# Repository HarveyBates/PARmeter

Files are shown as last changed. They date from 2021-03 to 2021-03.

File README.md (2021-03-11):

# PARmeter
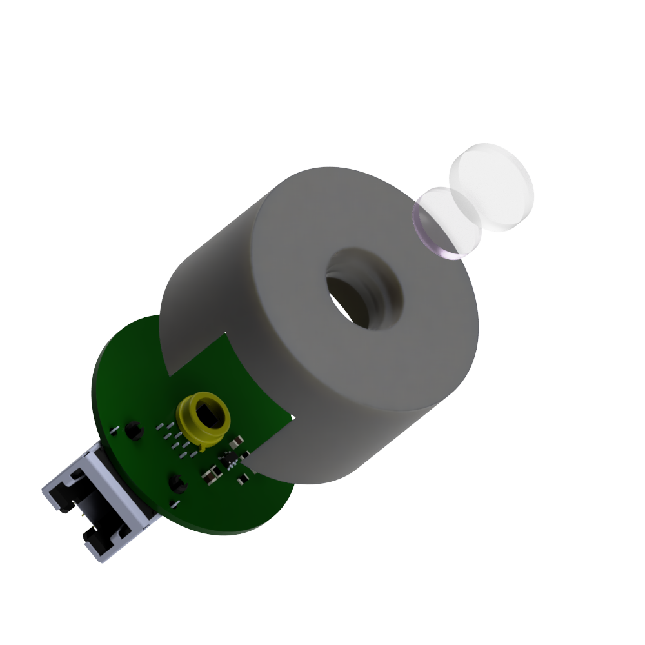
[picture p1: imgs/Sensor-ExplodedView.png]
## Introduction

**P**hotosynthetic **A**ctive **R**adiation (**PAR**) meters are designed to measure light intensity that has a wavelength between ~400 and 700 nm. This range represents the usable range for photosynthesising organims. This information is important for (amongst other things):

1. Studying photosynthesis
2. Calibrating plant growth light fixtures
3. Calibrating aqurarium LED arrays 

Readings are usually represented as the number of moles of photons per meter squared per second (**&mu;E m<sup>-2</sup> s<sup>-1</sup>** or **&mu;mol m<sup>-2</sup> s<sup>-1</sup>**). 

PAR meters differ from **l**uminous fl**ux** (**lux**) meters in that lux meters are typically used to measure wavelengths specific to human vision rather than those avaliable to photosynthesising organisms. Unlike PAR meters, lux meters require different coefficents for different light sources (white light, warm white light, blue, green, cyan etc.); therefore, they need to be calibrated for each light quality used. 

### Photodiode response

PAR meters are quite expensive when compared to lux meters as PAR meters require a virtually flat spectral response between the 400 and 700 nm wavelength range. This spectral response depends upon the photodiode used for detection. Typically, photodiodes have a varied wavelength specific response and as such only a few have ideal characteristics for PAR meters.

<p align="middle">
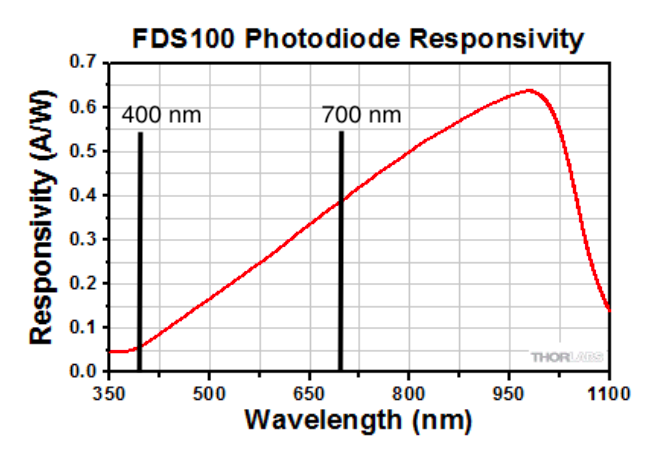
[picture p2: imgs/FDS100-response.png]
  
</p>

For this design I am using the [FDS100](https://www.thorlabs.com/thorproduct.cfm?partnumber=FDS100) (Silicon Photodiode) from ThorLabs. As its response is farily linear through the wavelength ranges of PAR. The increase in responsitivity with increasing wavelength is as a result of increasing [photon energy](https://en.wikipedia.org/wiki/Photon_energy).

### Cutoff filter

As can be seen from the photodiode responsitivity figure, the FDS100 photodiode is very responsive in wavelengths greater than 700 nm, therefore it is important that a short-pass filter is used to block these wavelengths from reaching the detector. 

<p align="middle">
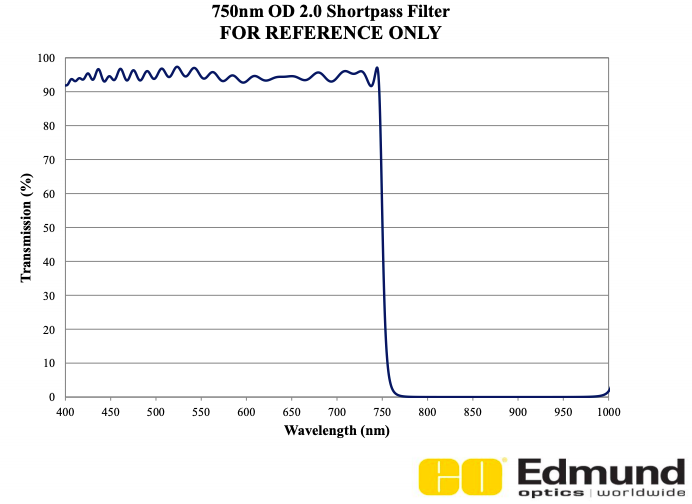
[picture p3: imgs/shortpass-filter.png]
  
</p>

Here I am using a 750 nm [short-pass filter](https://www.edmundoptics.com/p/750nm-125mm-dia-od-20-shortpass-filter/43482/) from Edmund optics. 750 nm is greater than the 400 - 700 nm range I mentioned earlier. However, the PAR range that is commonly used was determined a long time ago and there is evidence in the literature that IR-wavlengths are important to photosynthesis.

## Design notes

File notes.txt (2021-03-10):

------ Mechanical / Optical ------
Filter:
	https://www.edmundoptics.com/p/750nm-125mm-dia-od-20-shortpass-filter/43482/

Photodiode:
	https://www.thorlabs.com/thorproduct.cfm?partnumber=FDS100

Cosine Corrector (Acrylic Sheet):
	https://koenigmachinery.com.au/products/new-frosted-acrylic?variant=34646481240232

------ Electronics ------

Amplifier:
	https://au.element14.com/texas-instruments/opa320aidbvt/op-amp-cmos-20mhz-5sot23/dp/3116339?st=opa320

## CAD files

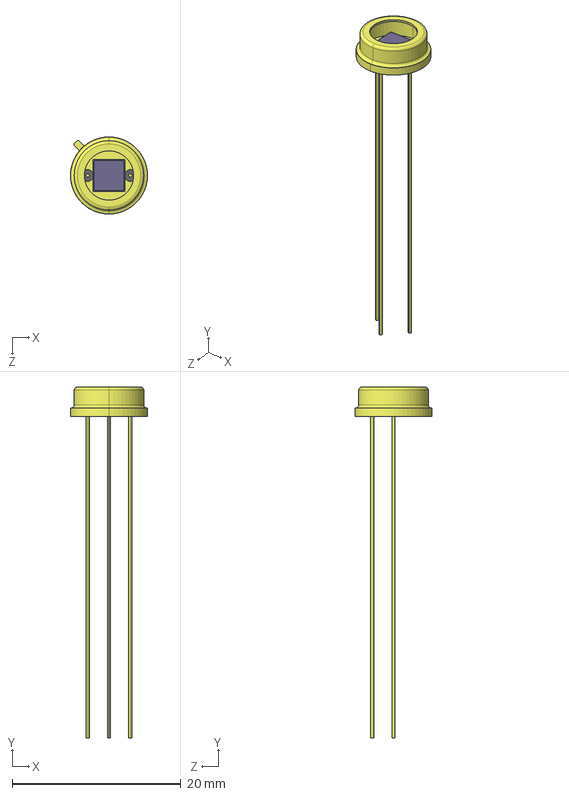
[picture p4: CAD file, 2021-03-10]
electronics/customlibrary/FDS100.step
9.14 x 41.6 x 9.14 mm

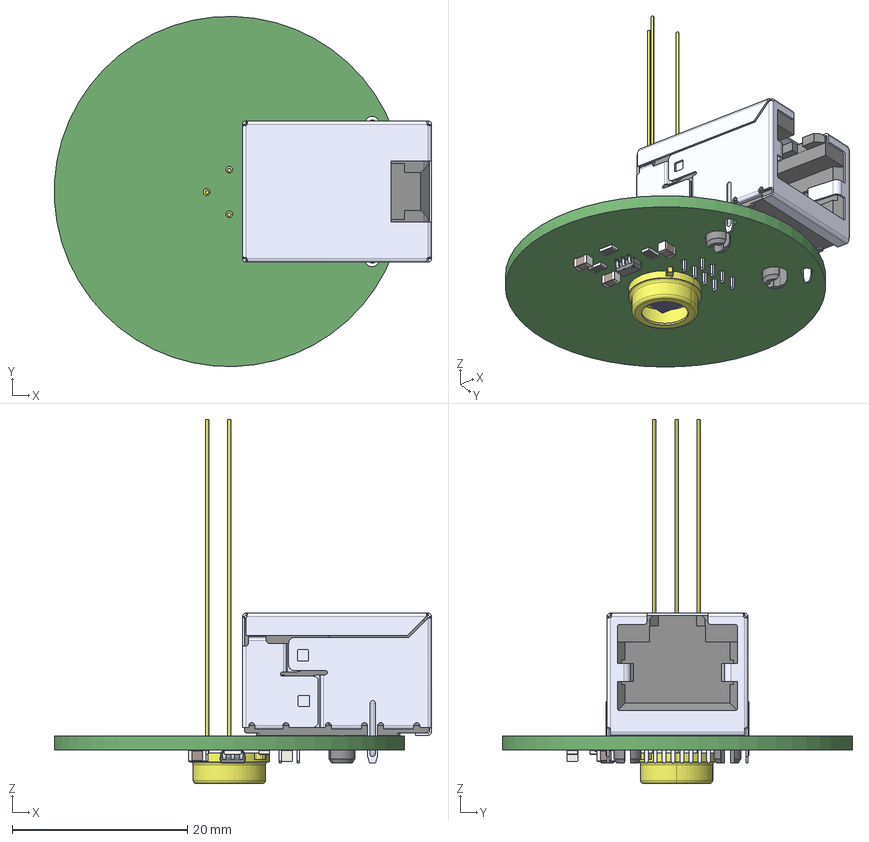
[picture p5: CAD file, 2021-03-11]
models/Sensor.step
43.1 x 40.0 x 41.6 mm

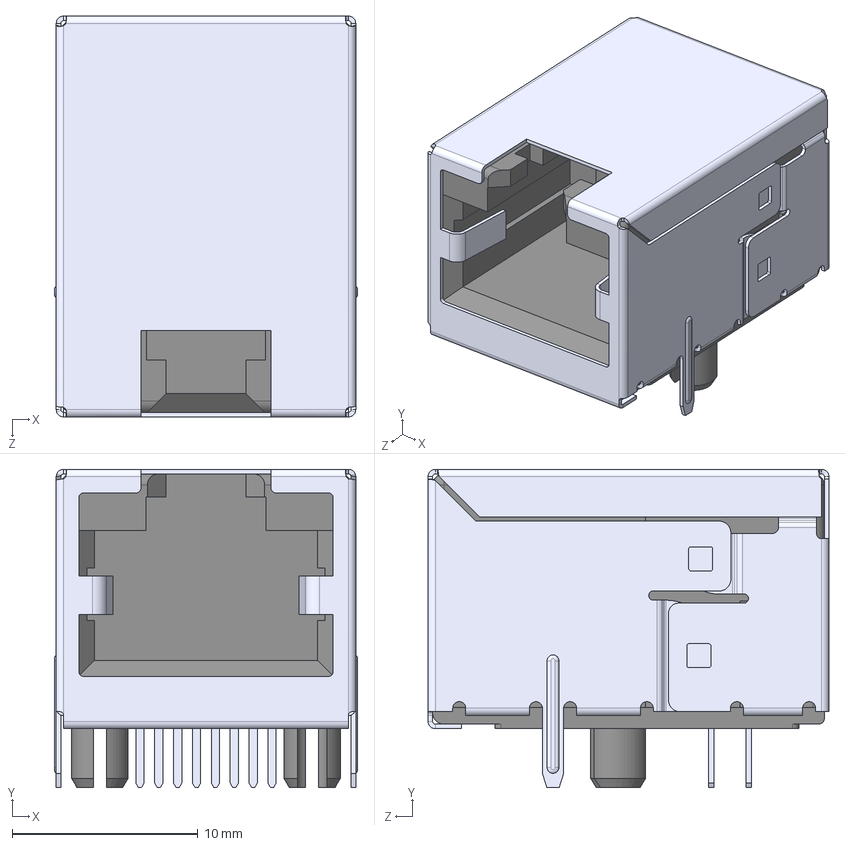
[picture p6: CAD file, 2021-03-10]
electronics/customlibrary/SS-60000-009.step
16.3 x 17.1 x 21.6 mm

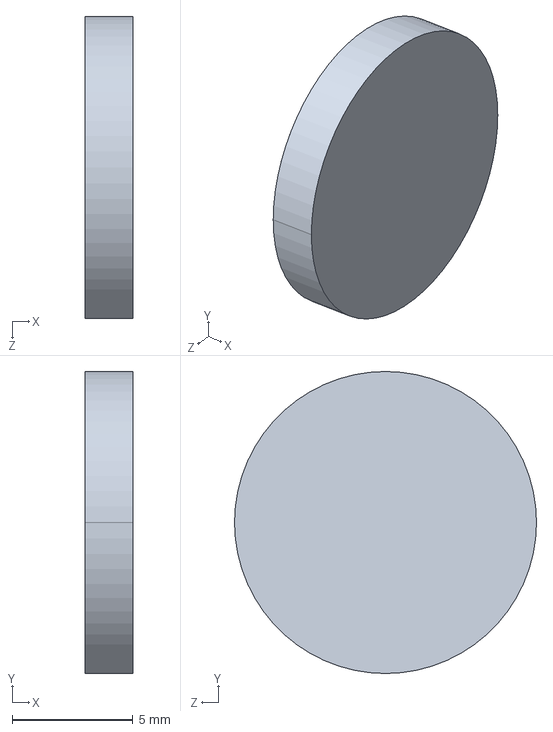
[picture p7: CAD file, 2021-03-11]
models/shortpass-filter-12.5mm.step
2.00 x 12.5 x 12.5 mm

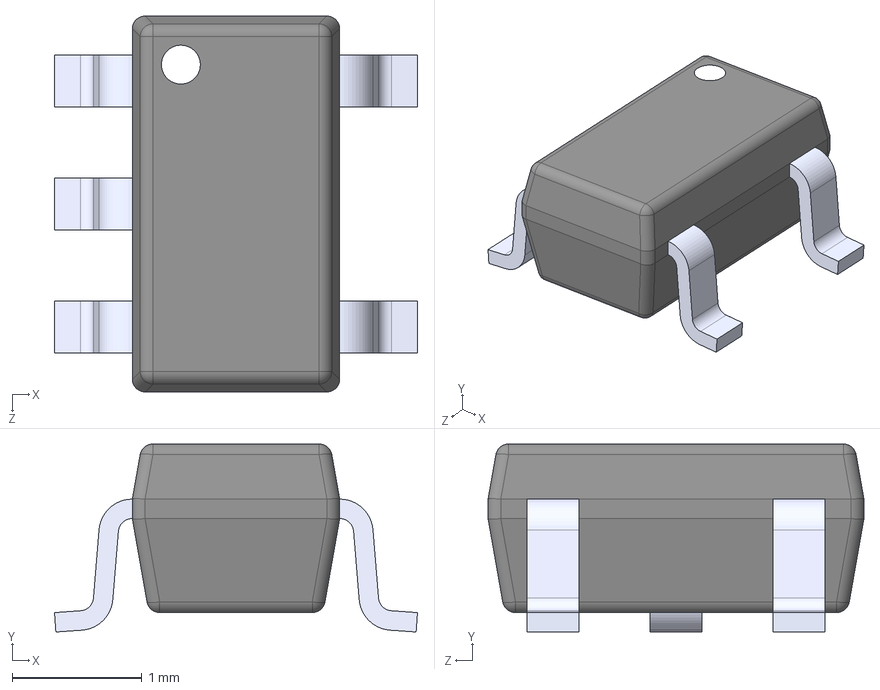
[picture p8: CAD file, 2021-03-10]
electronics/customlibrary/OPA320AIDBVT.step
2.80 x 1.45 x 2.90 mm

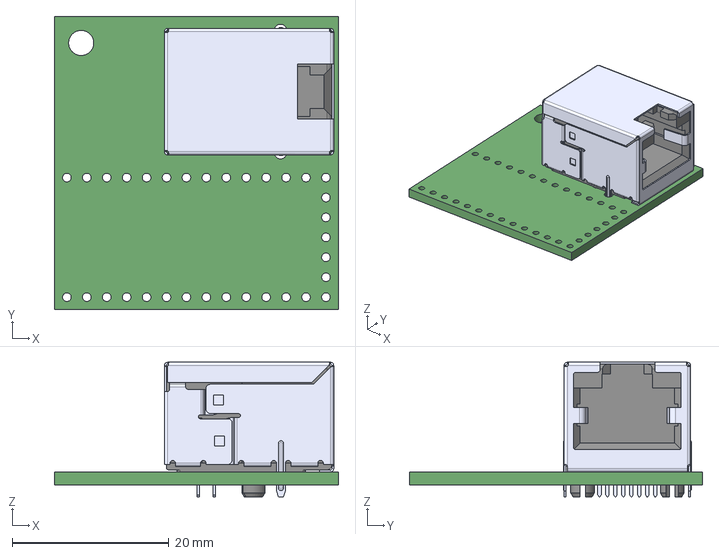
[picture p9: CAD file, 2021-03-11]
models/Controller.step
36.2 x 37.4 x 17.1 mm

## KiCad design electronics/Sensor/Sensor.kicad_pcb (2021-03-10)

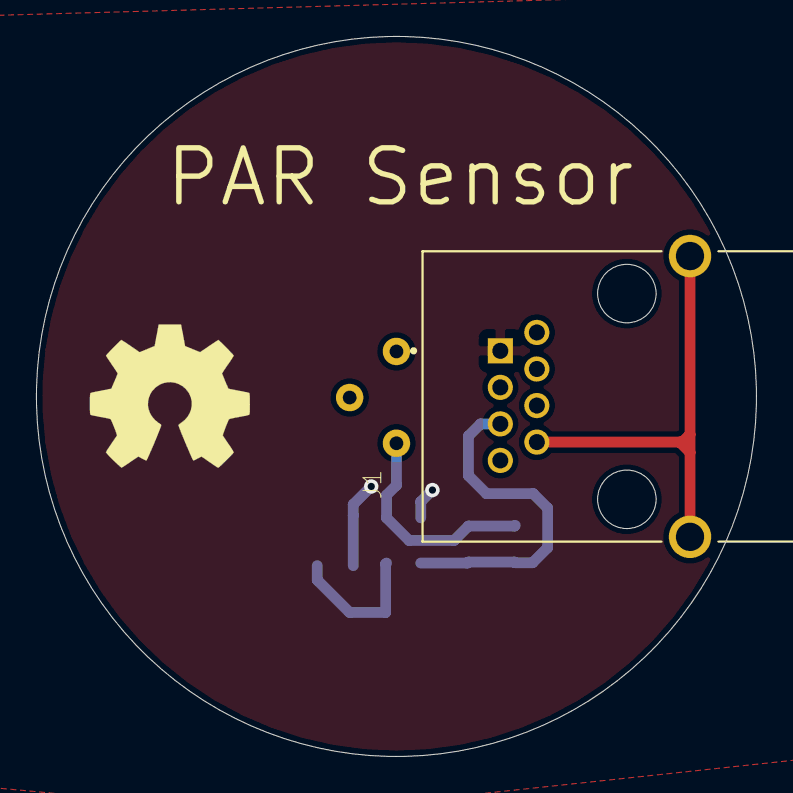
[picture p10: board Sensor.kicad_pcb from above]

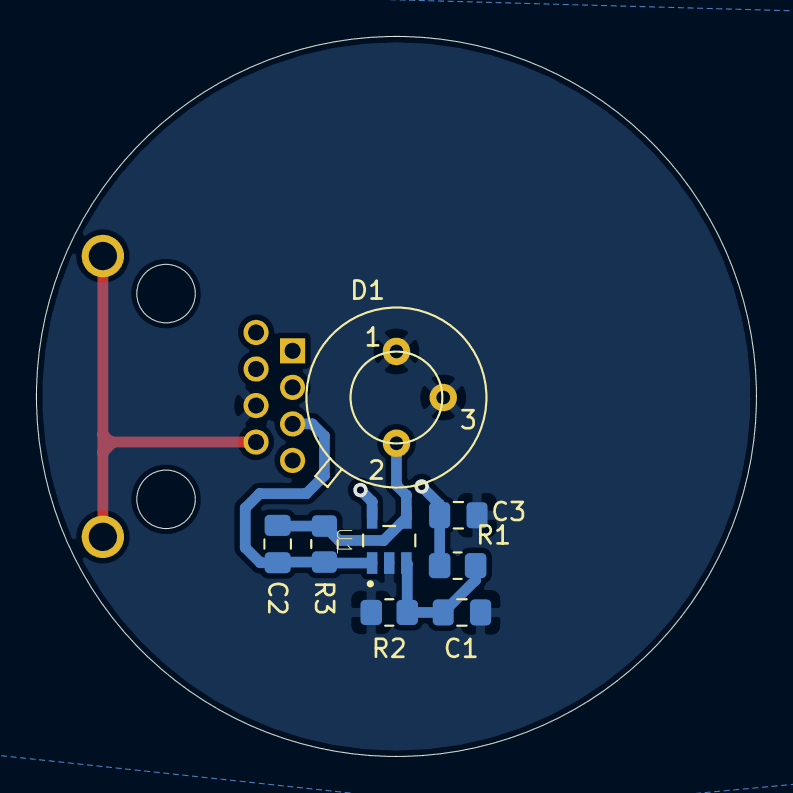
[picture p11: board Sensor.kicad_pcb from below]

Board: 2 copper layers, 40.0 x 40.0 mm, 9 parts (8 on the bottom side), 6 nets.

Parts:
C1, C3: 100nF; C_0805_2012Metric_Pad1.18x1.45mm_HandSolder
C2: 1pF; C_0805_2012Metric_Pad1.18x1.45mm_HandSolder
D1: FDS100
J1: SS-60000-009; BEL_SS-60000-009
R1: 20K; R_0805_2012Metric_Pad1.20x1.40mm_HandSolder
R2: 5; R_0805_2012Metric_Pad1.20x1.40mm_HandSolder
R3: 50K; R_0805_2012Metric_Pad1.20x1.40mm_HandSolder
U1: OPA320AIDBVT; OPA320AIDBVT5-SOT-23

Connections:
/3.3V: C3.2, J1.1, R1.1, U1.5
/AnalogGND: C1.2, C3.1, D1.1, D1.2, J1.4, R2.2, U1.2
/Fout: C2.1, J1.6, R3.1, U1.1
/SensorGND: J1.8, J1.S1, J1.S2
unnamed: C1.1, R1.2, R2.1, U1.3
unnamed: C2.2, D1.3, R3.2, U1.4

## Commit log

2021-03-10 create circuit board
    [Sensor.kicad_pcb, Sensor.sch, TeensySide.sch]
2021-03-10 rm kicad folders
2021-03-10 split controller and sensor + add gerbers
    [Controller-B_Cu.gbr, Controller-B_Mask.gbr, Controller-B_Paste.gbr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]
2021-03-11 added models and update readme
    [Controller.step, Sensor.step, shortpass-filter-12.5mm.step]
